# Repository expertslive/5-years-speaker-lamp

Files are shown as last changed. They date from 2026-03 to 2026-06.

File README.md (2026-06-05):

# High Five Hive — Setup Instructions

*Experts Live Netherlands · 5 Years · A thank you to our five-time speakers*

---

Thank you for being part of the Experts Live Netherlands community for **five years in a row**. This cube was made especially for you — a home for the four crystal cubes you collected at each edition, lit up to show them at their best.

Inside this box you'll find:

- The **High Five Hive** display cube (navy blue)
- A **USB-C power cable**
- Any spare screws or parts

---

## What's inside the cube

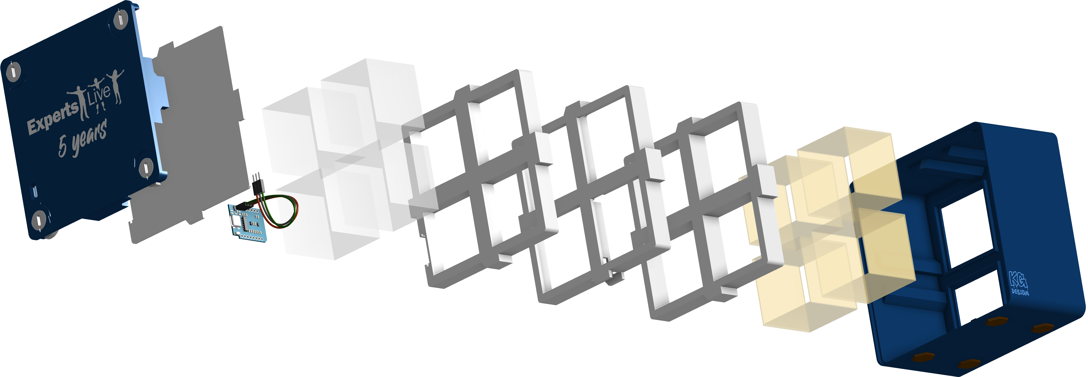
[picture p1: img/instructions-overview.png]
Overview of all components


The cube consists of several layers assembled from front to back:

- **Outer housing** — the dark navy blue shell
- **Crystal cube holders** — four individual compartments for each of your yearly speaker cubes
- **LED frames** — multiple layers holding the LED strip and cubes in place
- **Back cover plate** — the panel with the *Experts Live / 5 years* logo, secured by four twist-lock corner screws
- **WLED controller** — a tiny Wi-Fi-enabled electronics board (ESP8266) that drives all the lights and connects to your network

If you ever have to remove/place the inner frames, pay attention to the numbers on the side for correct placement:

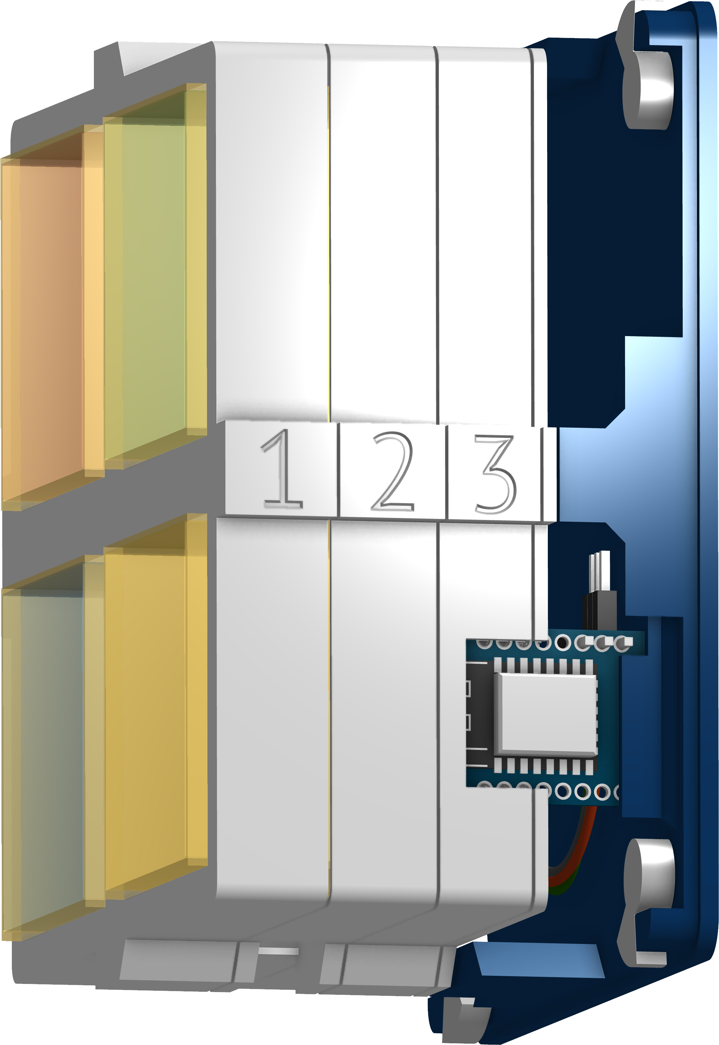
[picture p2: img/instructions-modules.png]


---

## Assembly

### Step 1 — Open the back cover

The back cover is secured by four **quarter-turn twist-lock screws** in the corners.

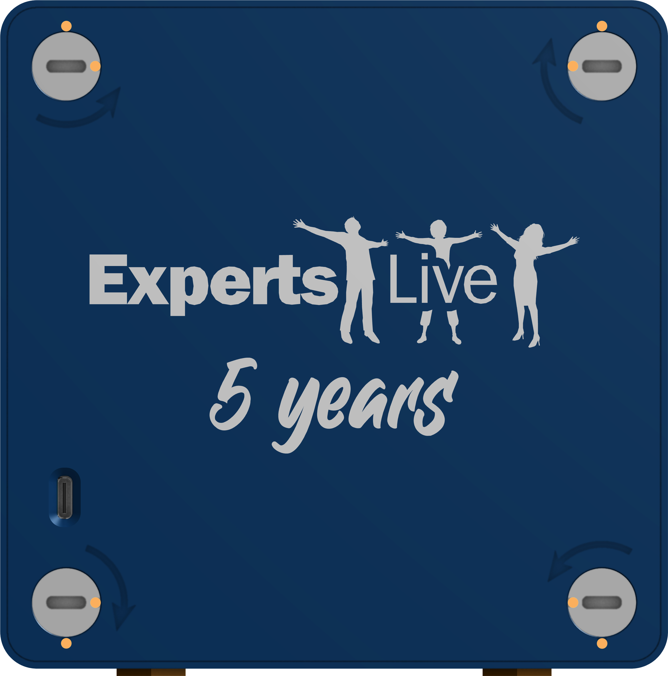
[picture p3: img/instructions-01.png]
Back cover with twist-lock screws


To open, insert the **connector end of the supplied USB-C cable** into each corner screw and rotate **in the opposite direction of the arrow**. Once all four screws are turned, the back panel will come free.

---

### Step 2 — Pull out the electronics board

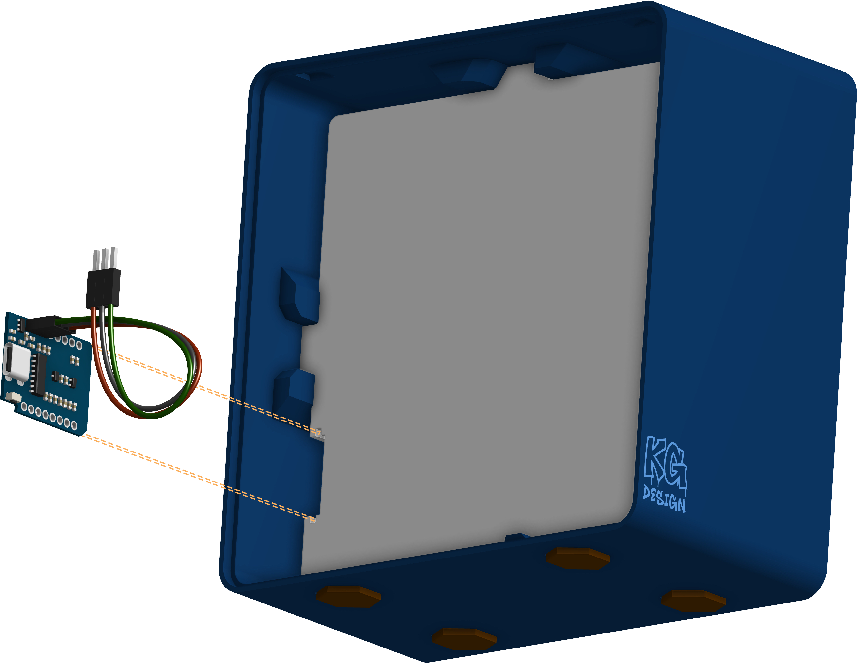
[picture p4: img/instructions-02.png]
ESP circuit board in housing


Gently pull the **WLED circuit board** out from its slot inside the housing. You only need to move it aside — **do not disconnect the LED strip connector** unless absolutely necessary.

> **If the LED strip connector did come loose**, reconnect it as follows before proceeding:
>
> | Wire colour | Pin | Position on circuitboard (viewed from above) |
> | --- | --- | --- |
> | **Red** | 5V | Left-most pin |
> | **Green** | Data | Middle pin |
> | **White** | GND | Right-most pin |

---

### Step 3 — Remove the white back panel

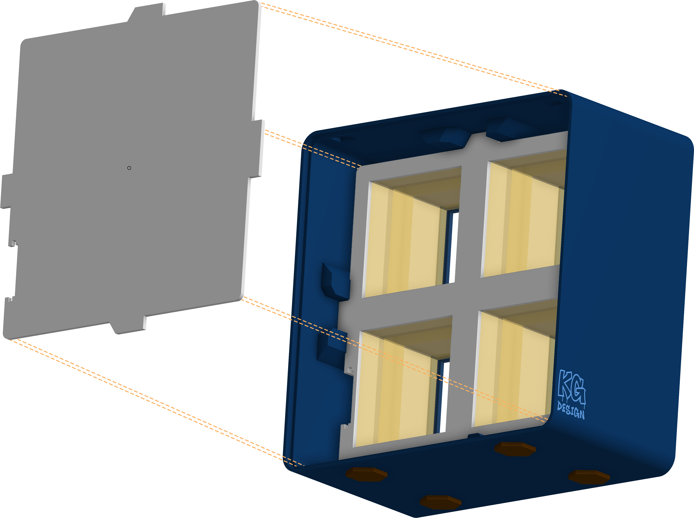
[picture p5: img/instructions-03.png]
White back panel removed


Lift out the **white cover plate** to expose the four openings for the crystal cubes inside the housing.

---

### Step 4 — Place your crystal cubes

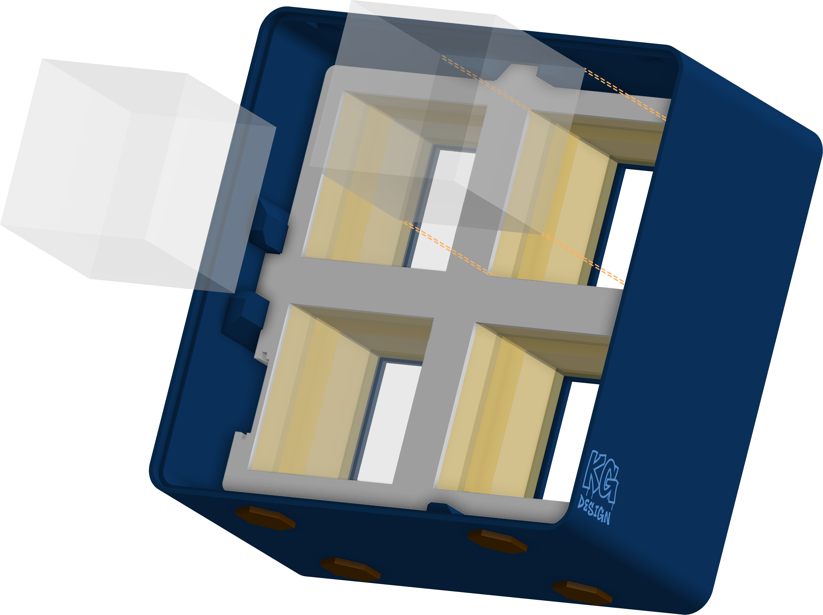
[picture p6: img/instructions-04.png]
Placing a crystal cube


Drop each of your four crystal speaker cubes into their compartment.

Each cube slides straight in and sits snugly in its slot. No forcing needed.

---

### Step 5 — Replace the white panel and reseat the board

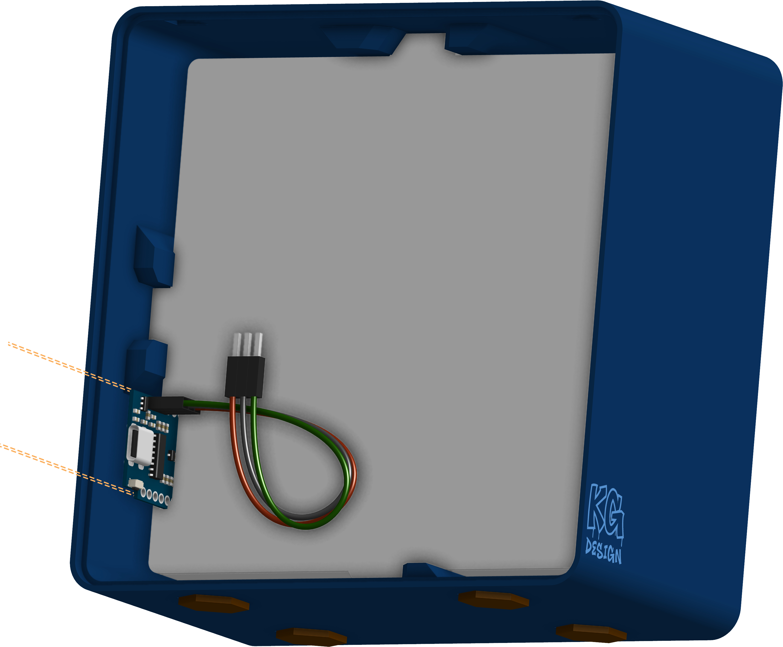
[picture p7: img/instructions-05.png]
Reseating the white panel and circuit board


Place the **white cover plate** back in position over the crystal cubes, then slide the **circuit board** back into its slot in the housing. Make sure the USB-C port aligns with the opening on the side of the back cover.

---

### Step 6 — Close and lock the back cover

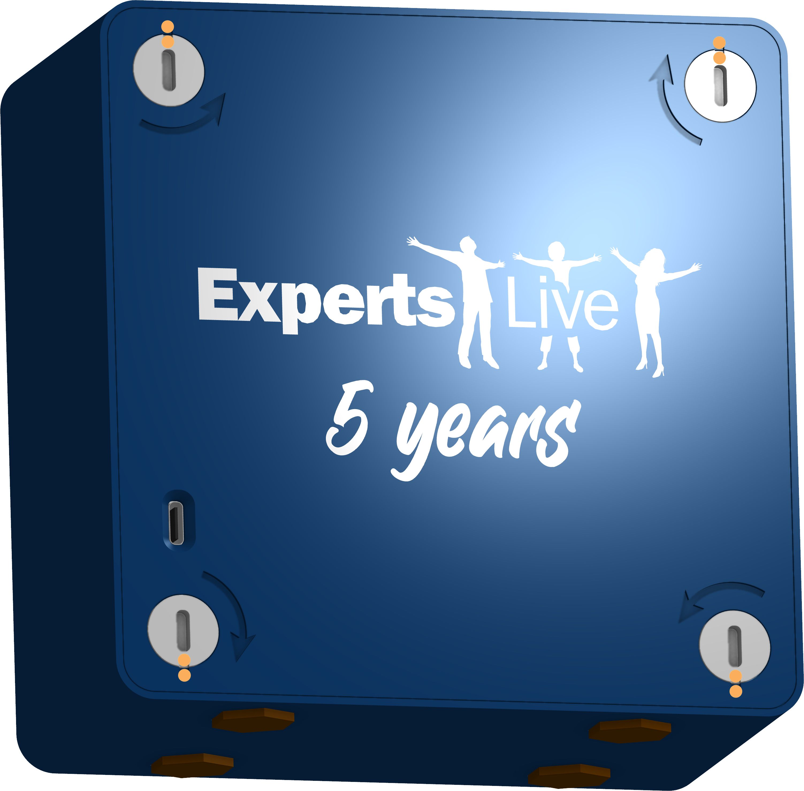
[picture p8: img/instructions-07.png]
Locking the back cover


Slide the back cover panel onto the housing and **lock all four corners in the direction of the arrows** using the USB-C connector. The arrows on the cover show the locked direction.

**Don't use excessive force!** If the screw wont turn freely, press down on the cover to make sure it slots in place neatly.

The cube is now fully assembled and ready to power on.

---

## Powering on

Connect a USB-C power cable (5V, at least 1A — a standard phone charger works perfectly) to the **USB-C port on the side** of the back panel.

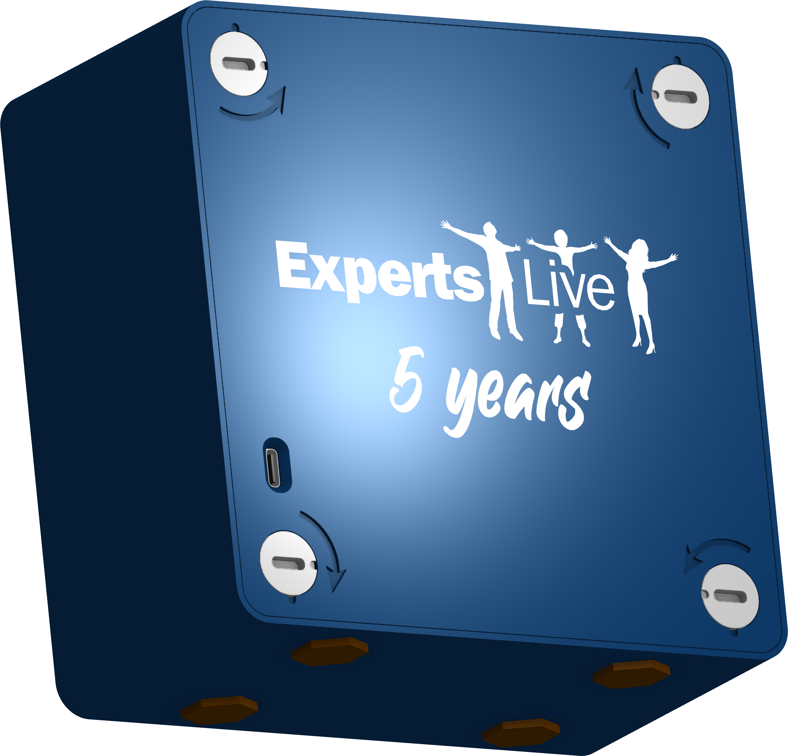
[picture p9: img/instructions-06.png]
USB-C port location


The cube will power on automatically. After a few seconds, the lights will start and the built-in show will begin — cycling through all the preset lighting effects.

---

## Connecting to the cube via Wi-Fi

The cube runs **WLED** — open-source LED control software with a built-in web interface. Out of the box it broadcasts its own open Wi-Fi network so you can connect and customise it without any technical setup.

### Step 1 — Connect to the cube's Wi-Fi

On your phone, tablet, or computer, open your Wi-Fi settings and connect to:

> **Network name:** `ExpertsLive-5-years`
> **Password:** wled1234

### Step 2 — Open the WLED interface

Once connected, open a browser and go to:

> **<http://expertslive.local>** (or <http://4.3.2.1>)

You will see the WLED interface with the custom Experts Live Netherlands background.

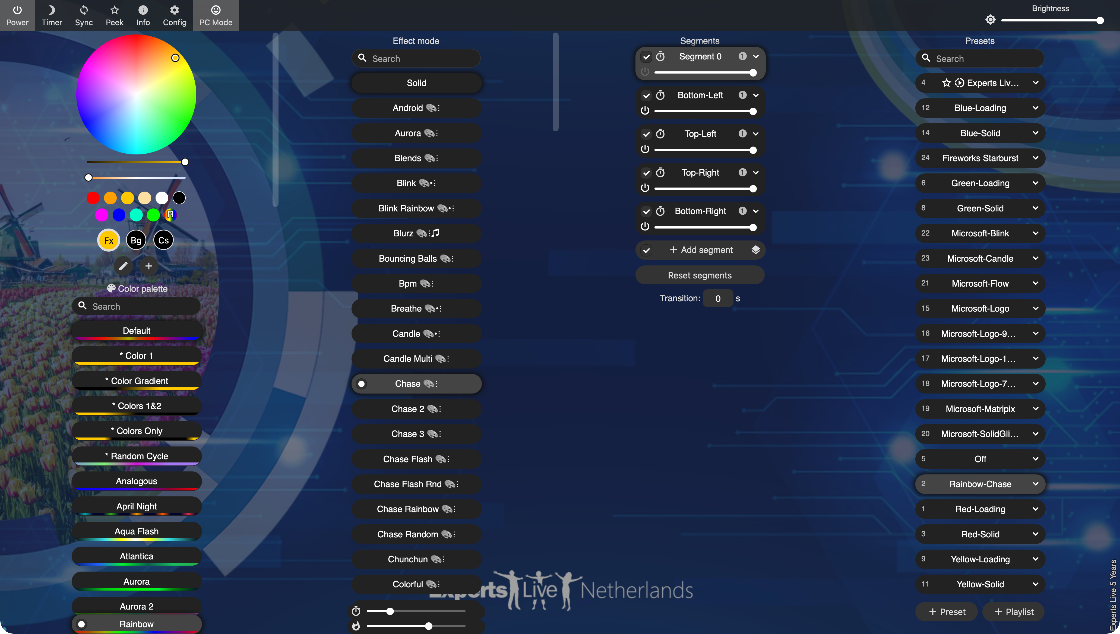
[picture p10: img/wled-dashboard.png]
WLED dashboard


### Using the WLED app (optional)

WLED has a free mobile app that makes it easy to control the cube from your phone. Search for **"WLED"** in the App Store or Google Play. When you open the app on the same Wi-Fi network, it will automatically discover the cube.

---

## Understanding the lights

The four cube compartments are each independently controlled. They are set up as named segments:

| Segment | Default colour |
| --- | --- |
| `Bottom-Left` | Blue |
| `Top-Left` | Red |
| `Top-Right` | Green |
| `Bottom-Right` | Yellow / Orange |

---

## Using the pre-built presets

A full set of lighting presets has been pre-loaded onto the cube. You can find them in the WLED interface under the **Presets** tab:

| Preset name | What it does |
| --- | --- |
| `Experts Live 5 Years` | **The main playlist** — cycles through all effects automatically |
| `Microsoft-Logo` | Each cube lights up in a Microsoft brand colour (blue / red / green / yellow) |
| `Microsoft-Matripix` | Matrix-style falling effect in brand colours |
| `Microsoft-Flow` | Smooth flowing colour per cube |
| `Microsoft-SolidGlitter` | Solid brand colours with a glitter sparkle |
| `Microsoft-Blink` | Fast blinking in brand colours |
| `Microsoft-Candle` | Warm candlelight flicker per cube |
| `Fireworks Starburst` | Fireworks bursting across all four cubes |
| `Rainbow-Chase` | A flowing rainbow chase across all four cubes |
| `Microsoft-Logo-90/180/270deg` | Microsoft colours rotated, used as a `boot sequence` |
| `Red/Green/Blue/Yellow-Solid/Loading` | Each cube individually lit in a single solid colour, used as a `boot sequence` |
| `Off` | All lights off, used as a `boot sequence` |

### The default playlist

By default, when you power the cube on it will automatically start the **"Experts Live 5 Years"** playlist. This cycles through all the presets in a scripted sequence — it starts with a loading animation, builds up to all four cubes lit and runs through the Microsoft-themed effects.
You don't need to do anything — just plug it in and enjoy the show.

If you want to set one preset as default, you can select the preset als make sure `Apply at boot` is selected before you click `Save`.

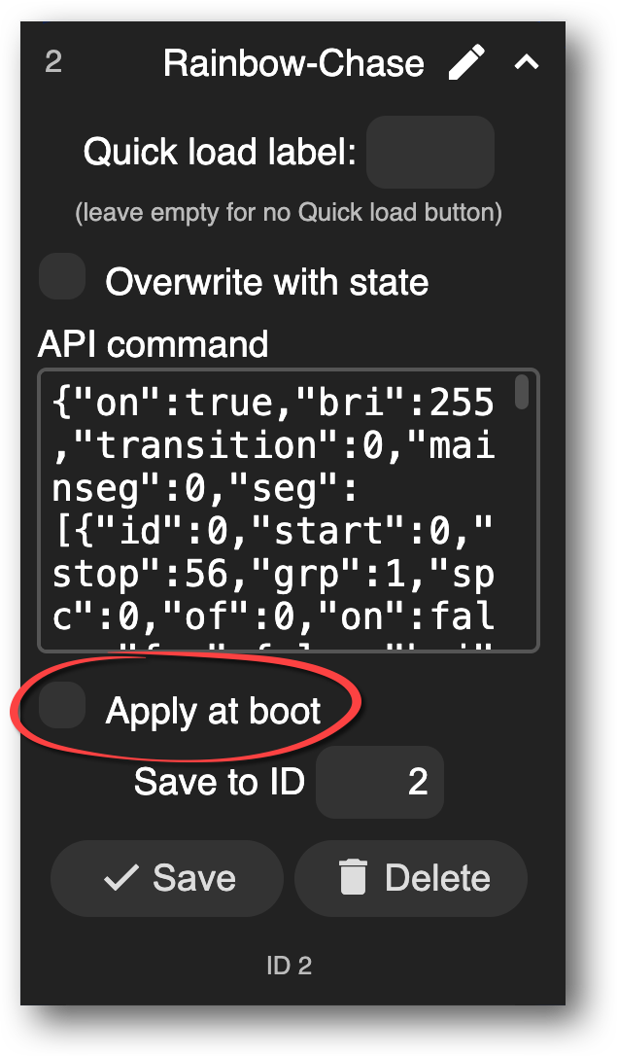
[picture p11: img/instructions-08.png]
Setting a preset


---

## Connecting to your home Wi-Fi (optional)

If you'd like to control the cube from your normal home network (so you don't need to switch Wi-Fi on your phone every time), you can connect it to your router:

1. Connect to `ExpertsLive-5-years` and open **<http://expertslive.local>** (or <http://4.3.2.1>)
2. Go to **Config → WiFi Setup**
3. Enter your home Wi-Fi network name and password and click **Save**
4. The cube will restart and join your home network
5. You can now reach it at **http://expertslive.local** from any device on the same network

> **Note:** After connecting to your home Wi-Fi, the `ExpertsLive-5-years` hotspot will no longer appear and will only show up if the device is unable to connect to a known network.

---

## Tips

- **Power:** Any USB-C charger (phone charger, laptop USB-C port, USB hub) will work. The cube draws under 1A at full brightness.
- **Brightness:** You can dim the lights in the WLED interface using the brightness slider — useful if you use it as a night-light ambience.
- **Custom effects:** WLED has hundreds of built-in effects and palettes. Feel free to explore — nothing you change can break the cube, and the pre-built presets are always there to return to.

---

## About this cube

Designed and built by [**Koos Goossens**](https://www.linkedin.com/in/koos-goossens/) for [Experts Live Netherlands](https://www.expertslive.nl)

This cube was created to give the four crystal cubes you earned over the years a permanent home and to say **thank you** for your continued contribution to the Microsoft community! 🙏🏻

*See you at the next one.*

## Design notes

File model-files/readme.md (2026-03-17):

# Model Files — High Five Hive

This folder contains all printable files for the ***"High Five Hive"*** speaker lamp, including the master Bambu Studio project file and the individual STL components.

---

## Project file

**`experts-live-high-five-hive.3mf`** — the Bambu Studio project file containing all four build plates, pre-arranged with their settings, filament assignments, and plate configurations. Open this file in Bambu Studio to print directly without any manual setup.

All plate settings (layer height, supports, print sequence) are embedded in the `.3mf`. A **textured PEI plate** is strongly recommended for both the housing and the rear cover to get a nice surface finish on the visible exterior faces.

---

## Build plates

| # | Plate | Contents | Material | Notes |
| --- | --- | --- | --- | --- |
| 1 | [Main housing](#plate-1--main-housing) | Outer shell | Dark Blue Matte PLA | Fuzzy skin on all exterior surfaces |
| 2 | [Rear cover](#plate-2--rear-cover) | Cover body, logo letters, mascot, screws, supports | Dark Blue + Ash Grey Matte PLA | Multi-material; many small objects |
| 3 | [Inner modules](#plate-3--inner-modules) | Cube holders, LED frame, holder plate | Ivory White Matte PLA | Single material |
| 4 | [Transparent cubes](#plate-4--transparent-cubes) | Light diffusion cubes (3 of 4) | Translucent PLA — Mellow Yellow | Vase mode; 0.8 mm nozzle; print 4th cube separately |

---

### Plate 1 — Main housing

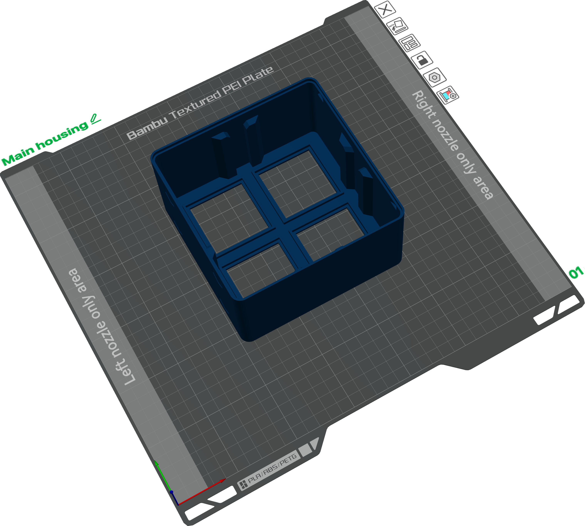
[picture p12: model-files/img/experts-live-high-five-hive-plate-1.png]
Plate 1 — Main housing


The outer dark navy blue shell of the lamp. Printed as a single object.

**Fuzzy skin** is applied to all exterior surfaces to give the housing a soft matte texture that hides layer lines and matches the look of the crystal speaker cubes.

| File | Description |
| --- | --- |
| `experts-live-high-five-hive-housing-main.stl` | Outer housing shell |

- **Material:** Bambu Labs Matte PLA — Dark Blue
- **Plate:** Textured PEI plate strongly recommended

---

### Plate 2 — Rear cover

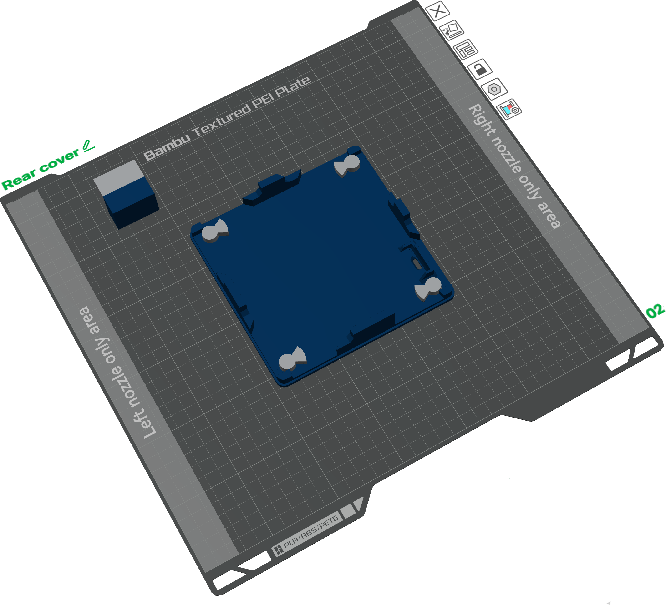
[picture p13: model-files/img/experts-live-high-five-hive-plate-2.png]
Plate 2 — Rear cover


The back panel with the *Experts Live / 5 Years* branding and the four quarter-turn twist-lock screws. This is a multi-material plate combining Dark Blue for the cover body and Ash Grey for the raised logo, lettering, and screw hardware.

The cover is intentionally built from many small individual objects rather than one solid model:

- **Individual letters** for "EXPERTS LIVE" and "5 YEARS" are separate STLs, allowing precise colour assignment to each character without painting.
- **Mascot logo** is split into multiple parts for the same reason.
- **Key supports** are custom-designed objects placed around each screw to prevent the screw from fusing with the cover during printing. They are printed in Ash Grey and can be broken free cleanly after the print.

| File | Description |
| --- | --- |
| `experts-live-high-five-hive-housing-cover.stl` | Main cover body |
| `experts-live-high-five-hive-housing-cover-01-ex.stl` … `09-e.stl` | Individual letters — *Experts Live* |
| `experts-live-high-five-hive-housing-cover-10-mascotte-*.stl` | Experts Live mascot logo (multiple parts) |
| `experts-live-high-five-hive-housing-cover-11-5.stl` … `16-S.stl` | Individual letters — *5 Years* |
| `experts-live-high-five-hive-screw-1.stl` … `screw-4.stl` | Quarter-turn twist-lock screws |
| `experts-live-high-five-hive-screw-1-key-support.stl` … `screw-4-key-support.stl` | Screw key supports (prevent fusing) |

- **Materials:** Bambu Labs Matte PLA — Dark Blue (cover body) + Ash Grey (logo, letters, screws, key supports)
- **Plate:** Textured PEI plate strongly recommended

---

### Plate 3 — Inner modules

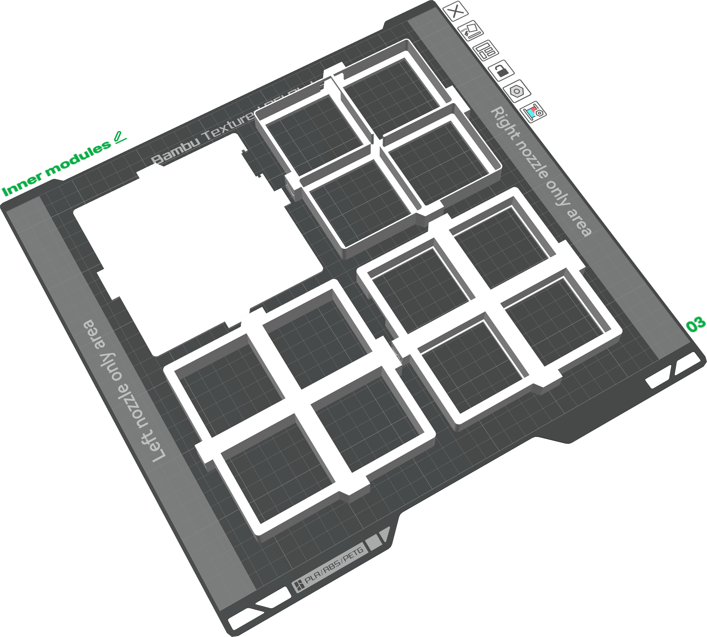
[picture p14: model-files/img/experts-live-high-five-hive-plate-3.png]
Plate 3 — Inner modules


The internal structural parts that hold the LED strip and crystal cubes in position inside the housing. All parts are printed in Ivory White.

| File | Description |
| --- | --- |
| `experts-live-high-five-hive-1-cube-holder.stl` | Cube holder frame — type 1 |
| `experts-live-high-five-hive-2-led-frame.stl` | LED strip frame |
| `experts-live-high-five-hive-3-cube-holder.stl` | Cube holder frame — type 3 |
| `experts-live-high-five-hive-3-cube-holder-plate.stl` | Cube holder backing plate |

- **Material:** Bambu Labs Matte PLA — Ivory White

---

### Plate 4 — Transparent cubes

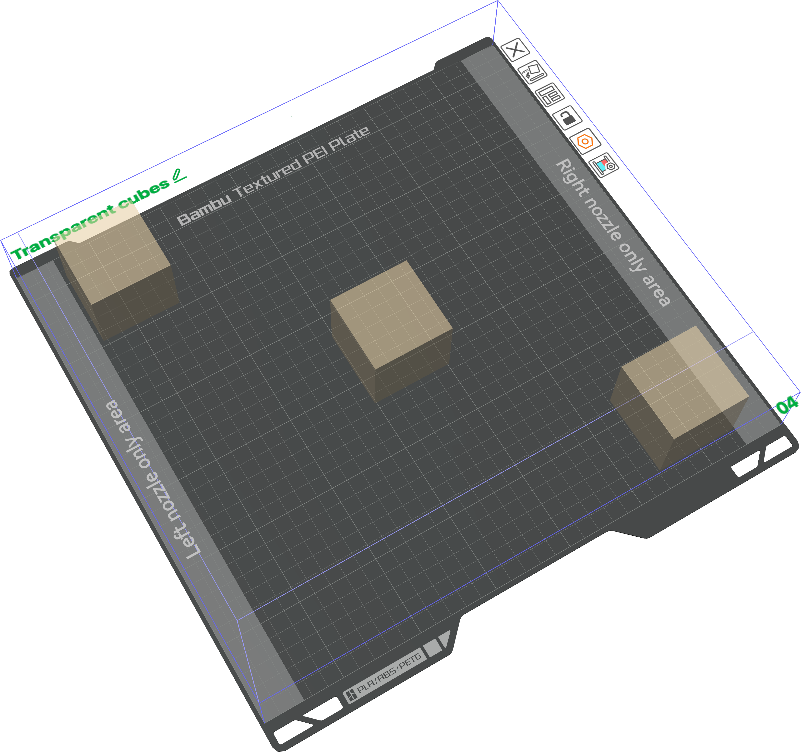
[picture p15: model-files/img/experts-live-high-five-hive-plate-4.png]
Plate 4 — Transparent cubes


The four small light-diffusion cubes that sit inside each compartment and scatter the LED light through the crystal speaker cubes above them. Three cubes are printed on this plate; **the fourth must be sent as a separate print**.

These cubes are printed in **vase mode** (single continuous spiral wall, no top/bottom layers) to maximise translucency and light diffusion.

- **Material:** Bambu Labs Translucent PLA — Mellow Yellow
- **Print sequence:** By object (sequential) — required for vase mode with multiple objects on one plate
- **Nozzle:** 0.8 mm recommended for a thicker, more even wall and better light diffusion
- **Plate:** Print 3 cubes first, then send a second print for cube #4

---

## Materials summary

| Material | Colour | Used for |
| --- | --- | --- |
| Bambu Labs Matte PLA | Dark Blue | Housing shell, rear cover body |
| Bambu Labs Matte PLA | Ash Grey | Logo letters, mascot, screws |
| Bambu Labs Matte PLA | Ivory White | All inner structural modules |
| Bambu Labs Translucent PLA | Mellow Yellow | Inner light-diffusion cubes |

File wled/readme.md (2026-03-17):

# WLED Configuration Files

This folder contains the WLED configuration for the **5 Years** speaker cubes lamp. Use these files to restore or clone the device if the ESP8266 controller needs to be replaced or reset.

---

## Files

| File | Purpose |
| --- | --- |
| `wled_cfg_experts-live-5-years.json` | Full device configuration (network, hardware, LED settings) |
| `wled_presets_experts-live-5-years.json` | All lighting presets and the boot playlist |
| `wled_ledmap.json` | Custom LED index remap for the physical strip layout |
| `wled-ui-bg-expertslive.jpg` | Custom background image shown in the WLED web UI |

---

## Device configuration summary

| Setting | Value |
| --- | --- |
| Device name | `Experts Live 5 Years` |
| mDNS hostname | `expertslive` → `http://expertslive.local` |
| Access point SSID | `ExpertsLive-5-years` (open, no password) |
| Access point IP | `4.3.2.1` |
| LED count | 56 |
| LED type | WS2812B |
| GPIO pin | 2 |
| Max current | 950 mA |
| Target FPS | 42 |
| Default brightness | 128 / 255 (~50%) |
| Boot preset | `4` — Experts Live 5 Years (playlist) |

---

## Presets

| ID | Name | Description |
| --- | --- | --- |
| `4` | `Experts Live 5 Years` | **Main boot playlist** — cycles through all effects automatically |
| `15` | `Microsoft-Logo` | Each cube in a Microsoft brand colour (blue / red / green / yellow) |
| `16` | `Microsoft-Logo-90deg` | Brand colours rotated 90° — used in boot sequence |
| `17` | `Microsoft-Logo-180deg` | Brand colours rotated 180° — used in boot sequence |
| `18` | `Microsoft-Logo-720deg` | Brand colours rotated 270° — used in boot sequence |
| `19` | `Microsoft-Matripix` | Matrix-style falling pixels in brand colours |
| `20` | `Microsoft-SolidGlitter` | Solid brand colours with glitter sparkle |
| `21` | `Microsoft-Flow` | Smooth flowing colour per cube |
| `22` | `Microsoft-Blink` | Fast blink in brand colours |
| `23` | `Microsoft-Candle` | Warm candlelight flicker per cube |
| `24` | `Fireworks Starburst` | Fireworks bursting across all four cubes |
| `2` | `Rainbow-Chase` | Flowing rainbow chase across all four cubes |
| `3` | `Red-Solid` | All cubes solid red |
| `8` | `Green-Solid` | All cubes solid green |
| `11` | `Yellow-Solid` | All cubes solid yellow |
| `14` | `Blue-Solid` | All cubes solid blue |
| `1` | `Red-Loading` | Red loading animation — used in boot sequence |
| `6` | `Green-Loading` | Green loading animation — used in boot sequence |
| `9` | `Yellow-Loading` | Yellow loading animation — used in boot sequence |
| `12` | `Blue-Loading` | Blue loading animation — used in boot sequence |
| `5` | `Off` | All LEDs off — used at end of boot sequence |

---

## LED map

The physical LED strip is wired so that three LEDs at the end of the strip (indices 53, 54, 55) are physically located after LED 10. The `wled_ledmap.json` remaps the logical indices to match the physical positions, ensuring segment boundaries align correctly with the four cube compartments.

---

## Restoring to a new device

1. Flash the device with [WLED](https://install.wled.me) (v0.15 or later recommended).
2. Connect to the `WLED-xxxxxx` access point and open `http://4.3.2.1`.
3. Go to **Config → Security & Updates** and upload `wled_presets_experts-live-5-years.json` under `Restore presets` using the **Restore** option.
4. Go to **Config → Security & Updates** and upload `wled_cfg_experts-live-5-years.json` unser `Restore configuration` using the **Restore** option.
5. Go to `http://expertslive.local/edit`, create a new file named `ledmap.json`, and paste in the contents of `wled_ledmap.json`.
6. Go to **Config → User Interface** and set `BG image URL` to `https://github.com/expertslive/5-years-speaker-lamp/blob/main/wled/wled-ui-bg-expertslive.jpg?raw=true`
7. Reboot the device. It will start the boot playlist automatically.

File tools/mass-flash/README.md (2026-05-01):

# WLED Mass-Flash Tool

Flashes multiple ESP8266 boards with WLED 0.15 + Experts Live 5 Years config in one USB step per board. After each flash the script discovers the board's IP on the local network (via MAC in ARP) and prints a clickable URL.

## Prerequisites (one-time, macOS)

    brew install esptool jq

`littlefs-python` is installed on demand by `build-fs.sh` via `python3 -m pip`.

If your boards use a CH340 USB-serial chip (common on cheap clones), install the WCH driver from https://www.wch.cn/downloads/CH341SER_MAC_ZIP.html.

## Build (once)

    WLED_WIFI_PSK='<wifi-password>' \
    WLED_AP_PSK='<device-ap-password>' \
    WLED_OTA_PASSWORD='<ota-password>' \
    ./build-fs.sh

Downloads the WLED 0.15.0 ESP8266 firmware and builds `build/littlefs.bin` containing:

- `cfg.json` — device config (LED count, boot preset, hardware pins, mDNS name)
- `wsec.json` — Wi-Fi/AP/OTA credentials supplied from environment variables
- `presets.json` — all lighting presets and the Experts Live boot playlist
- `ledmap.json` — physical-to-logical LED index remap

## Flash a single board

    ./flash.sh

Plug in the ESP8266 via USB, run the command, wait ~75s, unplug.

## Flash multiple boards in a loop

    ./flash.sh --loop

The script waits for a USB-serial device, flashes it, prints the board's IP, then waits for you to unplug before moving on to the next.

## Flash one specific port (when multiple devices are plugged in)

    ./flash.sh --port /dev/cu.usbserial-10

Useful on a workstation that hosts multiple flashing sessions at the same time.

## IP discovery overrides

By default `flash.sh` uses the interface from `route get default` and sweeps that interface's `/24` prefix. Override this when the active LAN is not on the default interface or when you need to force the scan range:

    ./flash.sh --iface en0
    ./flash.sh --subnet 192.168.1.0/24

## Per-flash output

    Board #7: /dev/cu.usbserial-10 -> MAC aa:bb:cc:dd:ee:ff -> http://192.168.1.123

Open the URL to verify the board joined Wi-Fi and is playing the boot playlist.

## Implementation notes

**LittleFS version:** WLED 0.15 on ESP8266 uses LittleFS v2.0 with `name_max=32`. `brew mklittlefs` writes v2.11 with `name_max=255` which WLED silently refuses to mount (it then reformats the partition with defaults, throwing away our config). We build the image via `littlefs-python` with the on-device parameters: `disk_version=0x00020000`, `name_max=32`, `block_size=8192`, `block_count=125` (total 1,024,000 bytes).

**Partition offset:** LittleFS lives at flash offset `0x300000` in WLED's ESP8266 4m1m partition layout. Not `0x200000` — a common misconfiguration.

**Credential storage:** WLED splits credentials between `cfg.json` (SSID + password length fields) and `wsec.json` (plaintext secrets). Injecting `psk` into `cfg.json` has no effect; credentials must be supplied through environment variables and written into `wsec.json` at build time.

**mDNS collisions:** all boards claim the same mDNS name `expertslive`. Only one can hold the name at a time, so hostname-based discovery (`expertslive.local`) is unreliable in bulk. The script uses ARP + MAC match instead — reliable even with many identical devices on one LAN.

**BG image URL (optional, per-browser):** WLED 0.15 stores the UI background URL in `localStorage`, not on the device, so it cannot be baked into the firmware image. Recipients who want the Experts Live background can set it themselves at **Config → User Interface → BG image URL** to:

    https://github.com/expertslive/5-years-speaker-lamp/blob/main/wled/wled-ui-bg-expertslive.jpg?raw=true

This is a one-time per-browser setting and does not affect LED behavior.

## Troubleshooting

**Board not detected:** Check the USB cable (some are charge-only). For CH340 clones, install the WCH driver.

**`Could not open <port>, the port is busy`:** another process is holding the serial port. Close any `install.wled.me` browser tab or other Web-Serial session, then retry.

**`Failed to connect to ESP8266`:** some clone boards don't auto-reset. Hold GPIO0 to GND while plugging in, then release.

**Device boots but doesn't join Wi-Fi:** verify the required `WLED_*` environment variables were set before building. Rebuild with `./build-fs.sh` if needed.

**IP not found within 60s:** the board flashed successfully but hasn't joined Wi-Fi yet, or the wrong LAN was scanned. Wait another 30s and check your router's DHCP list, or re-run with `--iface <name>` / `--subnet <prefix>`.

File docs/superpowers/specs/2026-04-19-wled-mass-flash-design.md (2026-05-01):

# WLED Mass-Flash Tool — Design

**Date:** 2026-04-19
**Context:** Flashing multiple ESP8266 boards with WLED + event-specific config for the Experts Live 5 Years speaker lamp.

## Problem

The current manual per-board process (see `wled/readme.md`) takes ~10–15 minutes per device: flash firmware via browser web installer, connect to device AP, upload presets JSON via web UI, upload config JSON via web UI, create `ledmap.json` via `/edit`, set BG image URL via UI, reboot. For multiple boards that becomes tedious AP-switching and file uploads.

We want a USB-only workflow: plug in, run one command, unplug.

## Approach

Flash **firmware + a pre-built LittleFS filesystem image** in a single `esptool` invocation. The LittleFS image contains the WLED config, presets, LED map, and generated secret config that WLED reads at boot, so the device comes up fully configured — no AP dance, no web UI steps.

Rejected alternatives:
- **Post-flash HTTP provisioning** (flash firmware, then script POSTs to WLED's JSON API): requires each Mac to hop onto each WLED AP in sequence. Fragile on macOS.
- **Parallel flashing via USB hub**: sequential is simple enough for this batch. Not worth the added complexity.

## Deliverables

New folder `tools/mass-flash/` in the repo:

```
tools/mass-flash/
├── flash.sh              # main — flashes one board per invocation (optional loop mode)
├── build-fs.sh           # one-time — builds LittleFS image from wled/ JSONs
├── build/                # gitignored — generated artifacts
│   ├── WLED_0.15.0_ESP8266.bin    # firmware (downloaded on first build)
│   ├── littlefs.bin                # filesystem image
│   ├── cfg-baked.json              # config copied from wled/ for the FS image
│   └── wsec-baked.json             # generated from WLED_* env vars, not committed
└── README.md
```

## Config transformations

The baked `cfg.json` derives from `wled/wled_cfg_experts-live-5-years.json`. Plaintext credentials are not committed; `build-fs.sh` generates `wsec.json` from environment variables at build time.

1. **Credentials** — WLED's export format uses password-length fields in `cfg.json` and stores plaintext values in `wsec.json`. The build step requires `WLED_WIFI_PSK`, `WLED_AP_PSK`, and `WLED_OTA_PASSWORD`, plus optional MQTT/Hue values, and writes them only into the generated build artifact.

2. **BG image URL** — WLED 0.15 stores this browser-side in `localStorage`, so it cannot be baked into the device image. The README documents it as an optional one-time per-browser setting.

`presets.json` and `ledmap.json` go into the LittleFS image unchanged.

## Flash command

```
esptool --port $(auto-detect) write-flash \
  0x0        build/WLED_0.15.0_ESP8266.bin \
  0x300000   build/littlefs.bin
```

The LittleFS partition offset depends on the WLED build's partition map and must be confirmed against the official WLED ESP8266 partition layout before first flash.

Port auto-detection: scan `/dev/cu.usbserial-*` and `/dev/cu.wchusbserial-*`. If exactly one match, use it. If zero or multiple, prompt the user.

## Per-board workflow

1. Plug ESP8266 into USB.
2. Run `./flash.sh`.
3. Script writes firmware + LittleFS, reads the board MAC via `esptool read-mac`, then discovers the DHCP IP by matching that MAC in ARP.
4. Script prints the discovered URL, or a clear "IP not found" warning if the board has not joined Wi-Fi yet.
5. (Optional) loop mode: script waits for device disconnect, then reconnect, then repeats automatically.

## Dependencies (macOS, one-time)

```
brew install esptool jq
```

`build-fs.sh` installs `littlefs-python` with `python3 -m pip` if needed so the same interpreter imports the module later. If the WCH USB-serial driver is not already installed, some boards (CH340-based clones) will not enumerate.

## Phases

1. **Build tooling** — write `build-fs.sh`, `flash.sh`, README. Produce `littlefs.bin` with current (untransformed) JSONs to verify the filesystem build process.
2. **Test on 1 board** — flash once, verify:
   - Device boots and joins the configured Wi-Fi network
   - Boot preset (playlist 4) plays
   - LED map is active (correct cube segmentation)
  - BG URL remains an optional per-browser setting
3. **Document BG URL limitation** — keep BG URL as an optional per-browser setting because it is not stored on the device.
4. **Flash remaining boards** — sequential, optionally with loop mode.

## Unknowns resolved in phase 2

- BG image URL is browser-local in WLED 0.15 and cannot be baked into the device.
- Generated `wsec.json` credentials are the correct way to provide Wi-Fi/AP/OTA secrets.
- LittleFS partition offset for the official WLED ESP8266 binary is `0x300000`.

## Success criteria

- A fresh ESP8266 plugged into USB, with one invocation of `flash.sh`, boots into the Experts Live 5 Years playlist with correct LED mapping and correct Wi-Fi connection — no AP-switching or web UI upload steps.
- Total hands-on time stays low because each board is plug in, flash, unplug.

## Out of scope

- Parallel flashing via USB hub
- Per-board unique identifiers (mDNS collisions, MQTT client IDs) — each unit will live on a different network post-event
- Automated GitHub Actions CI for the tool — one-time event use

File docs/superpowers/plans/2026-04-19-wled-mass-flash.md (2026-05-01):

# WLED Mass-Flash Tool Implementation Plan

> **For agentic workers:** REQUIRED SUB-SKILL: Use superpowers:subagent-driven-development (recommended) or superpowers:executing-plans to implement this plan task-by-task. Steps use checkbox (`- [ ]`) syntax for tracking.

**Goal:** Build a USB-only flashing workflow (`flash.sh`) that takes a blank ESP8266 to a fully configured WLED device in a single command, so multiple Experts Live speaker-lamp boards can be provisioned in one sitting.

**Architecture:** Two bash scripts in `tools/mass-flash/`. `build-fs.sh` runs once to download the WLED firmware binary, generate `wsec.json` from environment variables, and build a LittleFS image from the JSON files in `wled/`. `flash.sh` runs once per board: auto-detects the USB-serial port, runs `esptool write-flash` with firmware + filesystem, reads the board MAC, and discovers the DHCP IP via ARP. The device comes up fully configured on the target WLAN with the correct boot playlist and LED map — no web UI uploads or AP-switching.

**Tech Stack:** bash, `esptool` (Python), `littlefs-python`, `curl` (firmware download), `jq` (JSON transformations). macOS host.

**Test strategy:** Bash tooling does not warrant unit-test infrastructure for a one-shot event. Each task ends with a **verification step** — run the script (or a fragment), inspect the output, confirm expectations. Phase 2 of the spec (one-board end-to-end test with real hardware) is the integration test.

**Implementation outcome:** The final implementation uses `esptool`, `littlefs-python`, a 1,024,000-byte LittleFS image at `0x300000`, `wsec.json` generated from environment variables, and ARP/MAC IP discovery. The BG image cannot be baked because WLED 0.15 stores it in browser `localStorage`.

---

## Task 1: Scaffold folder + README skeleton + .gitignore

**Files:**
- Create: `tools/mass-flash/README.md`
- Create: `tools/mass-flash/.gitignore`
- Create: `tools/mass-flash/build/.gitkeep`

- [ ] **Step 1: Create folder structure**

```bash
mkdir -p tools/mass-flash/build
touch tools/mass-flash/build/.gitkeep
```

- [ ] **Step 2: Write `.gitignore` to exclude built artifacts**

`tools/mass-flash/.gitignore`:
```
build/*
!build/.gitkeep
```

- [ ] **Step 3: Write README skeleton**

`tools/mass-flash/README.md`:
```markdown
# WLED Mass-Flash Tool

Flashes multiple ESP8266 boards with WLED + Experts Live 5 Years config in one USB step per board.

## Prerequisites (one-time, macOS)

    brew install esptool jq

`littlefs-python` is installed on demand by `build-fs.sh` via `python3 -m pip`.

If your boards use a CH340 USB-serial chip (common on cheap clones), install the WCH driver from https://www.wch.cn/downloads/CH341SER_MAC_ZIP.html.

## Build (once)

    ./build-fs.sh

Downloads the WLED firmware and builds `build/littlefs.bin` with baked config.

## Flash a single board

    ./flash.sh

Plug in the ESP8266 via USB, run the command, wait ~45s, unplug.

## Flash in a loop (for multiple boards)

    ./flash.sh --loop

Script waits for each new USB-serial device, flashes it, prompts for the next.
```

- [ ] **Step 4: Verify structure**

```bash
ls -la tools/mass-flash/
```
Expected: `.gitignore`, `README.md`, `build/` directory present.

- [ ] **Step 5: Commit**

```bash
git add tools/mass-flash/
git commit -m "Scaffold tools/mass-flash/ folder and README"
```

---

## Task 2: Dependency-check preamble in build-fs.sh

**Files:**
- Create: `tools/mass-flash/build-fs.sh`

- [ ] **Step 1: Write dependency-check script**

`tools/mass-flash/build-fs.sh`:
```bash
#!/usr/bin/env bash
set -euo pipefail

SCRIPT_DIR="$(cd "$(dirname "${BASH_SOURCE[0]}")" && pwd)"
REPO_ROOT="$(cd "$SCRIPT_DIR/../.." && pwd)"
BUILD_DIR="$SCRIPT_DIR/build"
WLED_DIR="$REPO_ROOT/wled"

require_cmd() {
  if ! command -v "$1" >/dev/null 2>&1; then
    echo "Missing: $1" >&2
    echo "Install with: $2" >&2
    exit 1
  fi
}

require_cmd esptool "brew install esptool"
require_cmd jq "brew install jq"
require_cmd curl "already in macOS"
require_cmd python3 "already in macOS"

mkdir -p "$BUILD_DIR"

echo "Dependencies OK."
```

- [ ] **Step 2: Make executable**

```bash
chmod +x tools/mass-flash/build-fs.sh
```

- [ ] **Step 3: Verify**

```bash
./tools/mass-flash/build-fs.sh
```
Expected: prints `Dependencies OK.` (install anything missing first).

- [ ] **Step 4: Commit**

```bash
git add tools/mass-flash/build-fs.sh
git commit -m "build-fs.sh: dependency preamble"
```

---

## Task 3: Firmware download in build-fs.sh

**Files:**
- Modify: `tools/mass-flash/build-fs.sh`

**Note on firmware source:** WLED's GitHub releases publish ESP8266 binaries at predictable URLs. The 0.15.0 ESP8266 release asset is `WLED_0.15.0_ESP8266.bin`. If WLED has published a newer 0.15.x stable, upgrade at the top of the script — there is no compelling reason to pin. Pin to a version this plan was tested with: **0.15.0**.

- [ ] **Step 1: Append firmware-download block**

Add to `tools/mass-flash/build-fs.sh` (after dependency checks):

```bash
WLED_VERSION="0.15.0"
FIRMWARE_URL="https://github.com/Aircoookie/WLED/releases/download/v${WLED_VERSION}/WLED_${WLED_VERSION}_ESP8266.bin"
FIRMWARE_BIN="$BUILD_DIR/WLED_${WLED_VERSION}_ESP8266.bin"

if [[ ! -f "$FIRMWARE_BIN" ]]; then
  echo "Downloading WLED $WLED_VERSION firmware..."
  curl -fL --retry 3 -o "$FIRMWARE_BIN" "$FIRMWARE_URL"
fi

ls -la "$FIRMWARE_BIN"
```

- [ ] **Step 2: Run**

```bash
./tools/mass-flash/build-fs.sh
```
Expected: downloads the `.bin` file, prints size. File should be between ~500KB and ~800KB (typical WLED ESP8266 binary).

- [ ] **Step 3: Verify it is a valid ESP8266 image**

```bash
esptool --chip esp8266 image-info tools/mass-flash/build/WLED_0.15.0_ESP8266.bin
```
Expected: output shows ESP8266 image header, segments, entry point — no parse errors.

- [ ] **Step 4: Commit**

```bash
git add tools/mass-flash/build-fs.sh
git commit -m "build-fs.sh: download and verify WLED ESP8266 firmware"
```

---

## Task 4: Generate wsec-baked.json from environment credentials

**Files:**
- Modify: `tools/mass-flash/build-fs.sh`

**Why this works:** WLED's config exporter replaces plaintext secrets with password-length fields to avoid leaking credentials. WLED reads plaintext values from `wsec.json`, so `build-fs.sh` generates that file from environment variables instead of storing secrets in Git.

- [ ] **Step 1: Append cfg/wsec generator**

Add to `tools/mass-flash/build-fs.sh`:

```bash
SOURCE_CFG="$WLED_DIR/wled_cfg_experts-live-5-years.json"
BAKED_CFG="$BUILD_DIR/cfg-baked.json"
BAKED_WSEC="$BUILD_DIR/wsec-baked.json"

: "${WLED_WIFI_PSK:?Set WLED_WIFI_PSK before running build-fs.sh}"
: "${WLED_AP_PSK:?Set WLED_AP_PSK before running build-fs.sh}"
: "${WLED_OTA_PASSWORD:?Set WLED_OTA_PASSWORD before running build-fs.sh}"
WLED_MQTT_PSK="${WLED_MQTT_PSK:-}"
WLED_HUE_KEY="${WLED_HUE_KEY:-}"

if [[ ! -f "$SOURCE_CFG" ]]; then
  echo "Missing source config: $SOURCE_CFG" >&2
  exit 1
fi

cp "$SOURCE_CFG" "$BAKED_CFG"

jq -n \
  --arg wifi_psk "$WLED_WIFI_PSK" \
  --arg ap_psk "$WLED_AP_PSK" \
  --arg mqtt_psk "$WLED_MQTT_PSK" \
  --arg hue_key "$WLED_HUE_KEY" \
  --arg ota_pwd "$WLED_OTA_PASSWORD" '{
  nw: { ins: [ { psk: $wifi_psk } ] },
  ap: { psk: $ap_psk },
  if: { mqtt: { psk: $mqtt_psk }, hue: { key: $hue_key } },
  pin: "",
  ota: { pwd: $ota_pwd, lock: false, "lock-wifi": false, aota: true }
}' > "$BAKED_WSEC"

echo "Wrote $BAKED_CFG and $BAKED_WSEC"
```

- [ ] **Step 2: Run**

```bash
./tools/mass-flash/build-fs.sh
```
Expected: `Wrote tools/mass-flash/build/cfg-baked.json and tools/mass-flash/build/wsec-baked.json`.

- [ ] **Step 3: Verify transformation**

```bash
jq '.nw.ins[0] | has("psk")' tools/mass-flash/build/wsec-baked.json
```
Expected: `true`. Do not print the credential value.

```bash
jq '.nw.ins[0] | has("pskl")' tools/mass-flash/build/cfg-baked.json
```
Expected: `false`.

- [ ] **Step 4: Commit**

```bash
git add tools/mass-flash/build-fs.sh
git commit -m "build-fs.sh: generate wsec from env credentials"
```

---

## Task 5: Build LittleFS image

**Files:**
- Modify: `tools/mass-flash/build-fs.sh`

**LittleFS sizing rationale:** WLED ESP8266 stock builds using the 4m1m layout reserve a **1,024,000 byte** LittleFS partition starting at flash offset `0x300000`. WLED 0.15 on ESP8266 uses LittleFS v2.0 with `name_max=32`, so the image is built with `littlefs-python` rather than `brew mklittlefs`.

- [ ] **Step 1: Append LittleFS build block**

Add to `tools/mass-flash/build-fs.sh`:

```bash
FS_STAGE="$BUILD_DIR/fs-stage"
LITTLEFS_BIN="$BUILD_DIR/littlefs.bin"

rm -rf "$FS_STAGE"
mkdir -p "$FS_STAGE"
cp "$BAKED_CFG"  "$FS_STAGE/cfg.json"
cp "$BAKED_WSEC" "$FS_STAGE/wsec.json"
cp "$WLED_DIR/wled_presets_experts-live-5-years.json" "$FS_STAGE/presets.json"
cp "$WLED_DIR/wled_ledmap.json" "$FS_STAGE/ledmap.json"

python3 - "$FS_STAGE" "$LITTLEFS_BIN" <<'PY'
import sys, os
from littlefs import LittleFS, UserContext

stage, out = sys.argv[1], sys.argv[2]
BLOCK_SIZE, BLOCK_COUNT = 8192, 125

ctx = UserContext(BLOCK_SIZE * BLOCK_COUNT)
fs = LittleFS(
    context=ctx,
    block_size=BLOCK_SIZE,
    block_count=BLOCK_COUNT,
    name_max=32,
    disk_version=0x00020000,
    mount=False,
)
fs.format()
fs.mount()

for fname in sorted(os.listdir(stage)):
    with open(os.path.join(stage, fname), 'rb') as r:
        data = r.read()
    with fs.open('/' + fname, 'wb') as w:
        w.write(data)
    print(f"  /{fname} ({len(data)} bytes)")

fs.unmount()
with open(out, 'wb') as f:
    f.write(bytes(ctx.buffer))
PY

echo "Wrote $LITTLEFS_BIN ($(stat -f%z "$LITTLEFS_BIN") bytes)"
```

- [ ] **Step 2: Run**

```bash
./tools/mass-flash/build-fs.sh
```
Expected: prints size of `littlefs.bin`. File size should equal `1024000` bytes.

- [ ] **Step 3: Verify contents**

```bash
python3 - <<'PY'
from littlefs import LittleFS, UserContext
with open('tools/mass-flash/build/littlefs.bin', 'rb') as f:
    ctx = UserContext(bytearray(f.read()))
fs = LittleFS(context=ctx, block_size=8192, block_count=125, name_max=32, disk_version=0x00020000)
print(fs.listdir('/'))
PY
```
Expected: lists `cfg.json`, `wsec.json`, `presets.json`, `ledmap.json` with non-zero sizes.

- [ ] **Step 4: Commit**

```bash
git add tools/mass-flash/build-fs.sh
git commit -m "build-fs.sh: build LittleFS image from wled/ configs"
```

---

## Task 6: flash.sh port auto-detection

**Files:**
- Create: `tools/mass-flash/flash.sh`

- [ ] **Step 1: Write flash.sh with port detection**

`tools/mass-flash/flash.sh`:
```bash
#!/usr/bin/env bash
set -euo pipefail

SCRIPT_DIR="$(cd "$(dirname "${BASH_SOURCE[0]}")" && pwd)"
BUILD_DIR="$SCRIPT_DIR/build"
FIRMWARE_BIN="$BUILD_DIR/WLED_0.15.0_ESP8266.bin"
LITTLEFS_BIN="$BUILD_DIR/littlefs.bin"
LITTLEFS_OFFSET=0x300000

if [[ ! -f "$FIRMWARE_BIN" || ! -f "$LITTLEFS_BIN" ]]; then
  echo "Build artifacts missing. Run ./build-fs.sh first." >&2
  exit 1
fi

detect_port() {
  # CP210x on macOS appears as /dev/cu.usbserial-*, CH340 as /dev/cu.wchusbserial-*
  local matches=()
  for p in /dev/cu.usbserial-* /dev/cu.wchusbserial-* /dev/cu.SLAB_USBtoUART; do
    [[ -e "$p" ]] && matches+=("$p")
  done
  if [[ ${#matches[@]} -eq 0 ]]; then
    echo "No USB-serial device found. Plug in an ESP8266 and retry." >&2
    exit 1
  fi
  if [[ ${#matches[@]} -gt 1 ]]; then
    echo "Multiple USB-serial devices found:" >&2
    printf '  %s\n' "${matches[@]}" >&2
    echo "Disconnect all but one and retry." >&2
    exit 1
  fi
  echo "${matches[0]}"
}

PORT="$(detect_port)"
echo "Detected port: $PORT"
```

- [ ] **Step 2: Make executable**

```bash
chmod +x tools/mass-flash/flash.sh
```

- [ ] **Step 3: Verify (no board plugged in)**

```bash
./tools/mass-flash/flash.sh
```
Expected: `No USB-serial device found. Plug in an ESP8266 and retry.` and exit code 1.

- [ ] **Step 4: Verify (one board plugged in)**

Plug in one ESP8266 via USB, then:
```bash
./tools/mass-flash/flash.sh
```
Expected: `Detected port: /dev/cu.usbserial-XXXX` (or `wchusbserial-XXXX`), then exits cleanly (flashing not yet implemented).

- [ ] **Step 5: Commit**

```bash
git add tools/mass-flash/flash.sh
git commit -m "flash.sh: USB-serial port auto-detection"
```

---

## Task 7: flash.sh — esptool write-flash + IP discovery

**Files:**
- Modify: `tools/mass-flash/flash.sh`

- [ ] **Step 1: Append flash + discovery block**

Add at the bottom of `tools/mass-flash/flash.sh`:

```bash
echo "Writing firmware + LittleFS..."
esptool --chip esp8266 --port "$PORT" write-flash \
  0x0                "$FIRMWARE_BIN" \
  "$LITTLEFS_OFFSET" "$LITTLEFS_BIN"

echo "Reading MAC..."
mac_output=$(esptool --chip esp8266 --port "$PORT" read-mac 2>&1)
mac=$(printf '%s\n' "$mac_output" | awk '/^MAC:/ {print $2; exit}')
echo "MAC: $mac"
echo "Done. Unplug and insert the next board."
```

- [ ] **Step 2: Verify `esptool` is available**

```bash
esptool version
```
Expected: version string.

- [ ] **Step 3: Flash one test board**

Plug in one ESP8266, then:
```bash
./tools/mass-flash/flash.sh
```
Expected output (summarized):
- `Writing firmware + LittleFS...` → two write blocks, both end `Hash of data verified.`
- `Reading MAC...` → shows the board MAC address
- IP discovery prints a URL after the board joins Wi-Fi
- `Done. Unplug and insert the next board.`

- [ ] **Step 4: Verify the flashed device**

Within a minute after flashing:
- Device joins the configured Wi-Fi network automatically (check router DHCP list or `http://expertslive.local`).
- LEDs begin playing the Experts Live boot playlist.
- WLED web UI loads and shows all presets and the correct device name.

If all three check out, proceed. If any fails, stop and debug before continuing.

- [ ] **Step 5: Commit**

```bash
git add tools/mass-flash/flash.sh
git commit -m "flash.sh: erase, write firmware+fs, verify via serial"
```

---

## Task 8: ~~Discover BG image URL field name~~ (DROPPED)

**Investigation outcome:** In WLED 0.15, the "BG image URL" setting is stored in the browser's `localStorage` (via the `wledUiCfg` key), not on the device. There is no server-side field to bake. The `skin.css` fallback also requires the browser's "Enable custom CSS" toggle (`comp.css` in localStorage) which is also browser-local. Therefore no device-side mechanism to propagate the BG image to every recipient exists in stock WLED 0.15.

**Decision:** drop Task 8 and Task 9. The BG image becomes an optional one-time per-browser step, documented in the tool README. The baked device config (boot playlist, LED map, Wi-Fi, presets) is unchanged by this decision.

---

## ~~Task 8/9: Bake BG URL~~ (DROPPED)

WLED 0.15 stores the UI background URL in browser `localStorage`, not on the device. The mass-flash image therefore cannot bake this setting. The README documents it as an optional one-time per-browser step instead.

---

## Task 10: Loop mode in flash.sh

**Files:**
- Modify: `tools/mass-flash/flash.sh`

- [ ] **Step 1: Wrap the main block in a loop when `--loop` is passed**

Restructure `tools/mass-flash/flash.sh` so the existing single-flash logic lives in a function `flash_one()`, and add a `--loop` dispatcher at the end. Final structure:

```bash
#!/usr/bin/env bash
set -euo pipefail

SCRIPT_DIR="$(cd "$(dirname "${BASH_SOURCE[0]}")" && pwd)"
BUILD_DIR="$SCRIPT_DIR/build"
FIRMWARE_BIN="$BUILD_DIR/WLED_0.15.0_ESP8266.bin"
LITTLEFS_BIN="$BUILD_DIR/littlefs.bin"
LITTLEFS_OFFSET=0x300000

if [[ ! -f "$FIRMWARE_BIN" || ! -f "$LITTLEFS_BIN" ]]; then
  echo "Build artifacts missing. Run ./build-fs.sh first." >&2
  exit 1
fi

detect_port() {
  local matches=()
  for p in /dev/cu.usbserial-* /dev/cu.wchusbserial-* /dev/cu.SLAB_USBtoUART; do
    [[ -e "$p" ]] && matches+=("$p")
  done
  if [[ ${#matches[@]} -eq 0 ]]; then return 1; fi
  if [[ ${#matches[@]} -gt 1 ]]; then
    echo "Multiple USB-serial devices found:" >&2
    printf '  %s\n' "${matches[@]}" >&2
    return 2
  fi
  echo "${matches[0]}"
}

wait_for_port() {
  echo "Waiting for board to be plugged in..."
  while true; do
    local port
    port="$(detect_port 2>/dev/null || true)"
    if [[ -n "$port" ]]; then echo "$port"; return 0; fi
    sleep 1
  done
}

wait_for_disconnect() {
  local port="$1"
  echo "Unplug the board to flash the next one."
  while [[ -e "$port" ]]; do sleep 1; done
  echo "Board unplugged."
}

flash_one() {
  local port="$1"
  echo "Detected port: $port"
  echo "Writing firmware + LittleFS..."
  esptool --chip esp8266 --port "$port" write-flash \
    0x0               "$FIRMWARE_BIN" \
    "$LITTLEFS_OFFSET" "$LITTLEFS_BIN"
  echo "Reading MAC..."
  mac_output=$(esptool --chip esp8266 --port "$port" read-mac 2>&1)
  mac=$(printf '%s\n' "$mac_output" | awk '/^MAC:/ {print $2; exit}')
  echo "MAC: $mac"
  echo "Done."
}

if [[ "${1:-}" == "--loop" ]]; then
  count=0
  while true; do
    port="$(wait_for_port)"
    count=$((count + 1))
    echo "--- Board #$count ---"
    flash_one "$port"
    wait_for_disconnect "$port"
    echo ""
  done
else
  port="$(detect_port)" || {
    echo "No USB-serial device found. Plug in an ESP8266 and retry." >&2
    exit 1
  }
  flash_one "$port"
  echo "Unplug and insert the next board."
fi
```

- [ ] **Step 2: Verify single-shot still works**

```bash
./tools/mass-flash/flash.sh
```
Expected: flashes the currently plugged-in board (or errors cleanly if none).

- [ ] **Step 3: Verify loop mode**

```bash
./tools/mass-flash/flash.sh --loop
```
Expected: prints `Waiting for board to be plugged in...`. Plug in a board — it flashes, then prints `Unplug the board to flash the next one.`. Unplug — script returns to waiting. Ctrl-C to exit.

Do not flash the full batch in this step. Just verify the state machine works for 2 boards.

- [ ] **Step 4: Commit**

```bash
git add tools/mass-flash/flash.sh
git commit -m "flash.sh: loop mode for sequential mass-flash"
```

---

## Task 11: Mass-flash run + documentation

**Files:**
- Modify: `tools/mass-flash/README.md`

- [ ] **Step 1: Update README with final workflow**

Append to `tools/mass-flash/README.md`:

```markdown
## Mass-flashing multiple boards

1. Run `./build-fs.sh` once. Commits any new firmware to the build cache.
2. Run `./flash.sh --loop`.
3. For each board:
   - Plug into USB
   - Wait for "Done." message (~30–45s)
   - Unplug
4. Ctrl-C when done.

Expected total time: 25–40 minutes.

## Troubleshooting

**Board not detected:** Check USB cable (some are charge-only). For CH340 clones, install the WCH driver.

**`Failed to connect to ESP8266` from esptool:** Hold GPIO0 to GND while plugging in, then release. Some clone boards don't auto-reset.

**Device joins Wi-Fi but no LEDs:** Power delivery. The first flash draws heavy current — USB may not provide enough for the LED strip. Powering the LED strip from its own supply during flashing is the fix.

**Device boots but doesn't join Wi-Fi:** Verify the required `WLED_*` environment variables were set before building. Rebuild with `./build-fs.sh` if needed.
```

- [ ] **Step 2: Flash all boards**

```bash
./tools/mass-flash/flash.sh --loop
```
Work through all boards. After each, do a quick smoke check on one representative board mid-run (boot playlist plays, joins Wi-Fi, UI loads with correct BG).

- [ ] **Step 3: Commit**

```bash
git add tools/mass-flash/README.md
git commit -m "Document mass-flash workflow and troubleshooting"
```

---

## Completion Checklist

- [ ] `./build-fs.sh` runs cleanly on a fresh checkout.
- [ ] `./flash.sh` (single) flashes one board in under a minute.
- [ ] `./flash.sh --loop` state machine works across 2+ boards.
- [ ] Test board: joins the configured Wi-Fi network, plays boot playlist, shows correct UI background without any manual step.
- [ ] All boards flashed and spot-checked.
- [ ] README documents workflow + troubleshooting.
- [ ] All intermediate commits pushed (or batched for a single PR — your call).

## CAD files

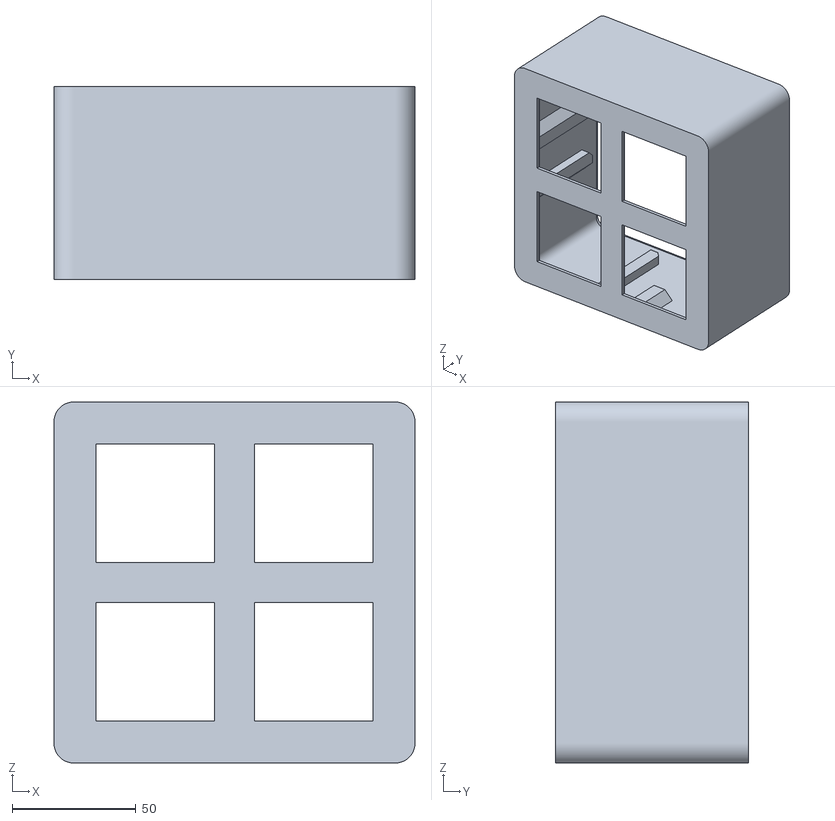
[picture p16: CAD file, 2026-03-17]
model-files/experts-live-high-five-hive-housing-main.stl
146.0 x 78.0 x 146.0

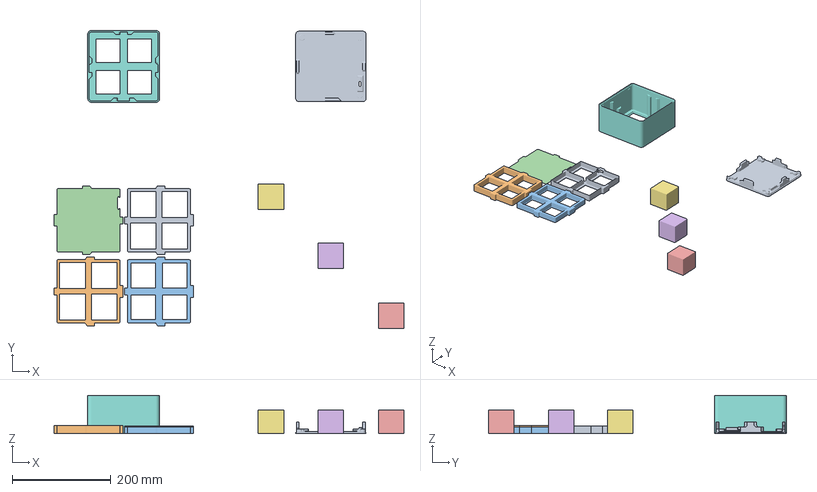
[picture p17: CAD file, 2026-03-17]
model-files/experts-live-high-five-hive.3mf
709.5 x 604.6 x 78.0 mm
Experts Live High Five Hive - 2 - LED Frame.stl
Experts Live High Five Hive - 1 - Cube Holder.stl
Experts Live High Five Hive - 3 - Cube Holder.stl
Experts Live High Five Hive - 3 - Cube Holder Plate.stl
Experts Live High Five Hive - Housing - main.stl
Experts Live High Five Hive - Part 48

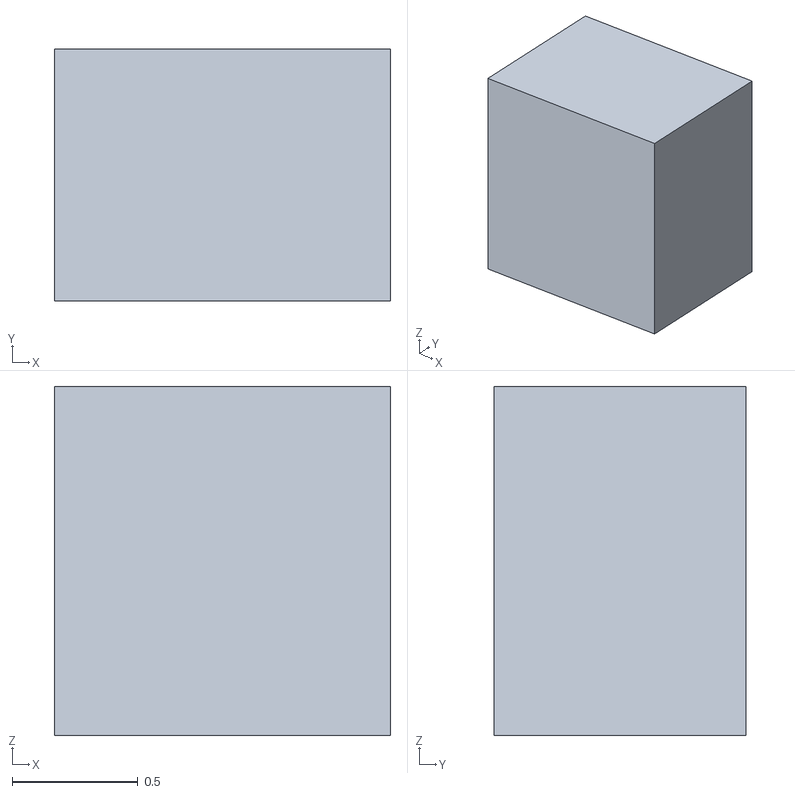
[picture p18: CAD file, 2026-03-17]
model-files/experts-live-high-five-hive-housing-cover-07-i-2.stl
1.34 x 1.00 x 1.39

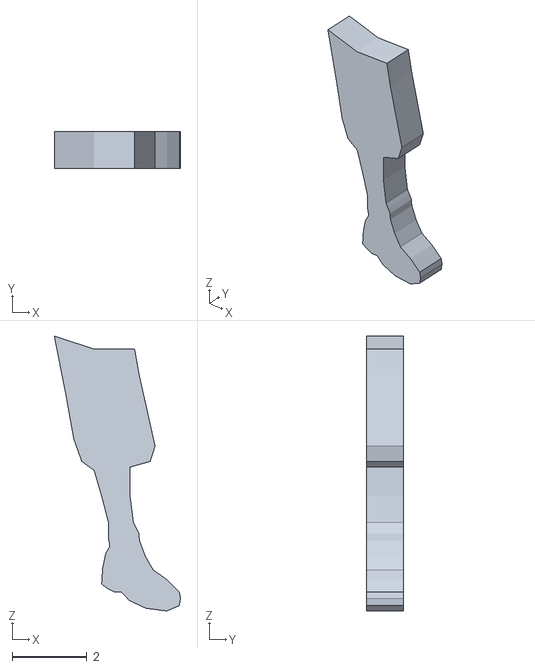
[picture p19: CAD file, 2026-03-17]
model-files/experts-live-high-five-hive-housing-cover-10-mascotte-2-2.stl
3.37 x 1.00 x 7.35

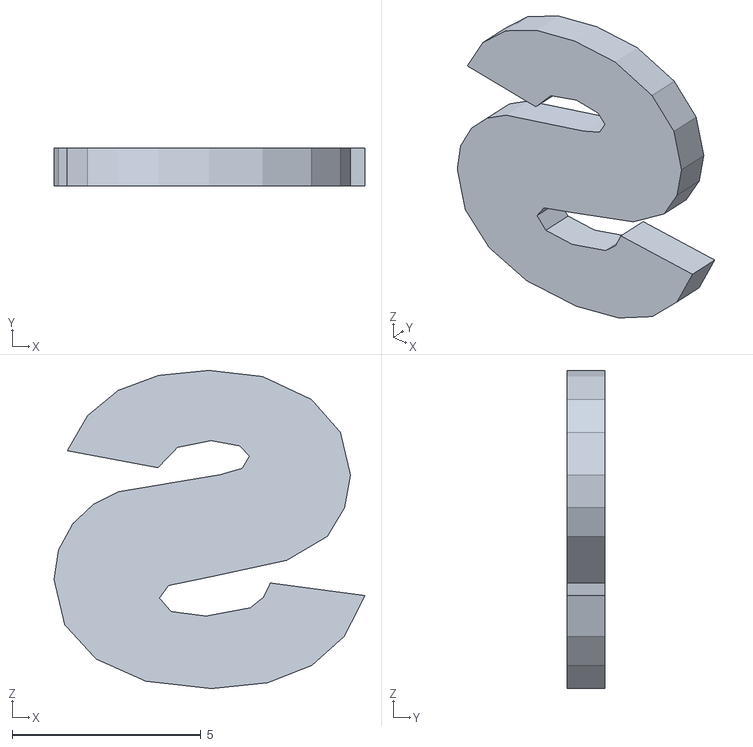
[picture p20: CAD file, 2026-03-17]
model-files/experts-live-high-five-hive-housing-cover-05-s.stl
8.25 x 1.00 x 8.44

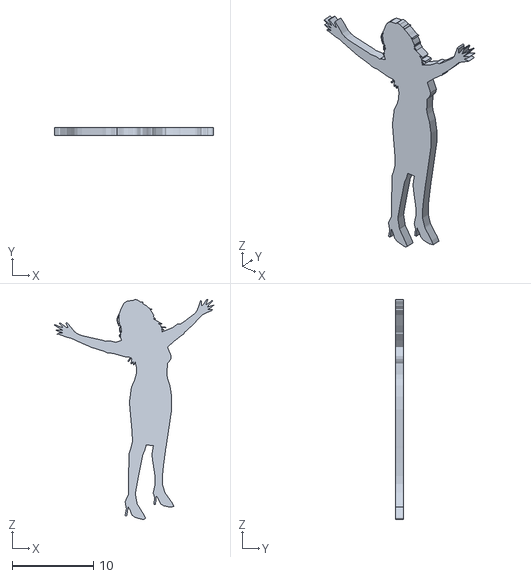
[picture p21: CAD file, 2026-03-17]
model-files/experts-live-high-five-hive-housing-cover-10-mascotte-3.stl
19.7 x 1.00 x 27.1

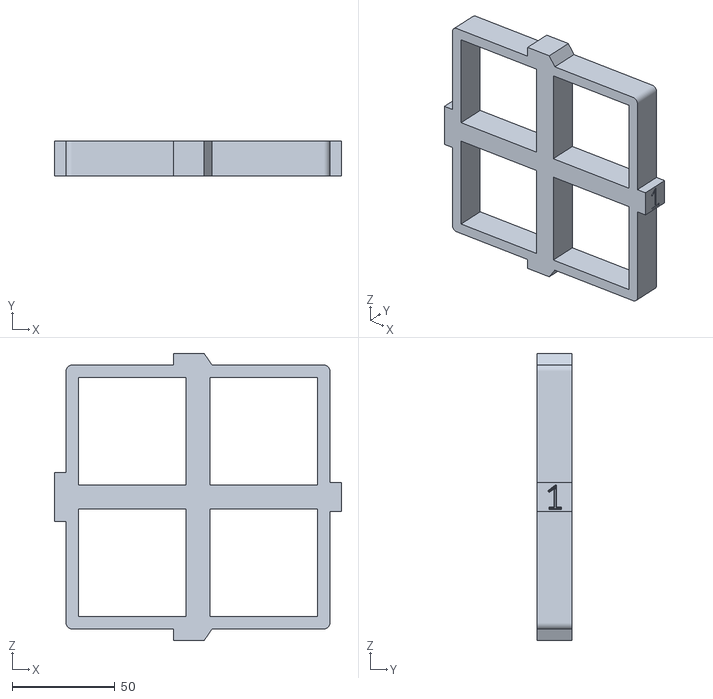
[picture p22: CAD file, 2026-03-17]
model-files/experts-live-high-five-hive-1-cube-holder.stl
139.6 x 17.0 x 139.6

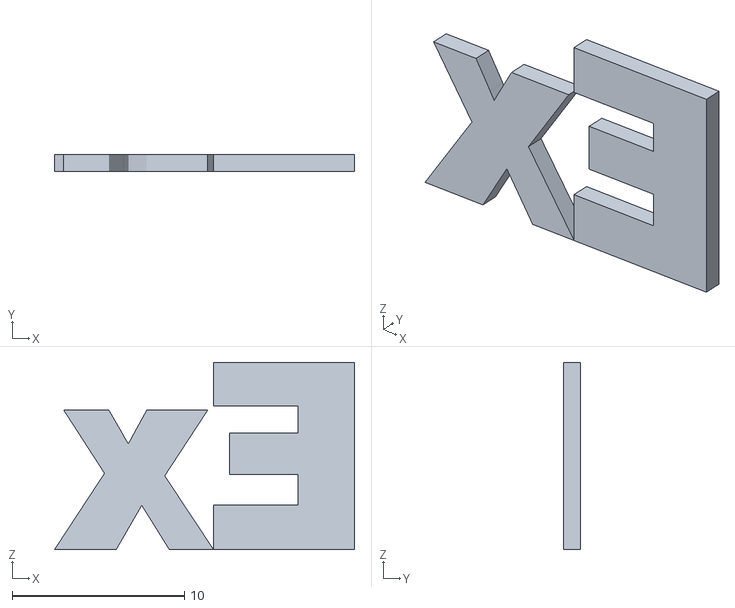
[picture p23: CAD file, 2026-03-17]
model-files/experts-live-high-five-hive-housing-cover-01-ex.stl
17.4 x 1.00 x 10.9

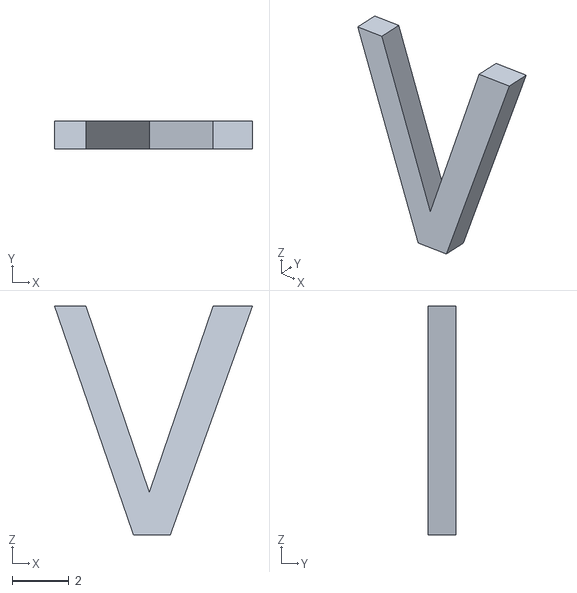
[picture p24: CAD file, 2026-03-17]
model-files/experts-live-high-five-hive-housing-cover-08-v.stl
6.96 x 1.00 x 8.04

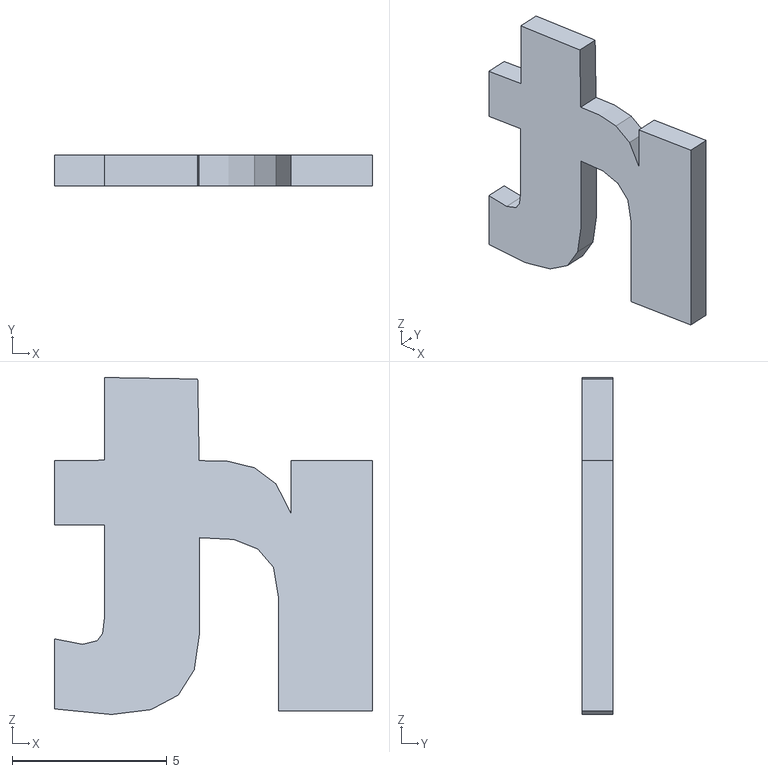
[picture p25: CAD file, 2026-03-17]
model-files/experts-live-high-five-hive-housing-cover-04-rt.stl
10.3 x 1.00 x 10.9

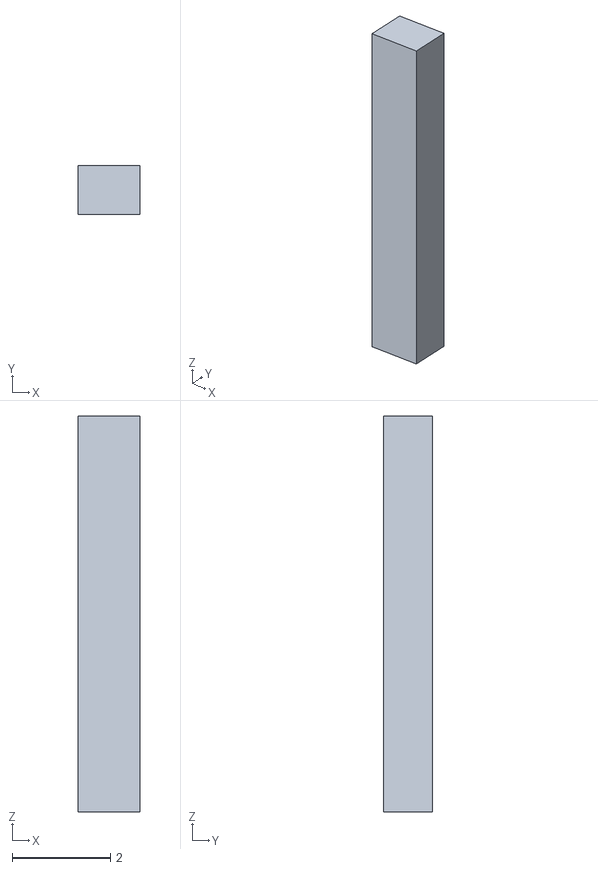
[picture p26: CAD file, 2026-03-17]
model-files/experts-live-high-five-hive-housing-cover-07-i-1.stl
1.25 x 1.00 x 8.04

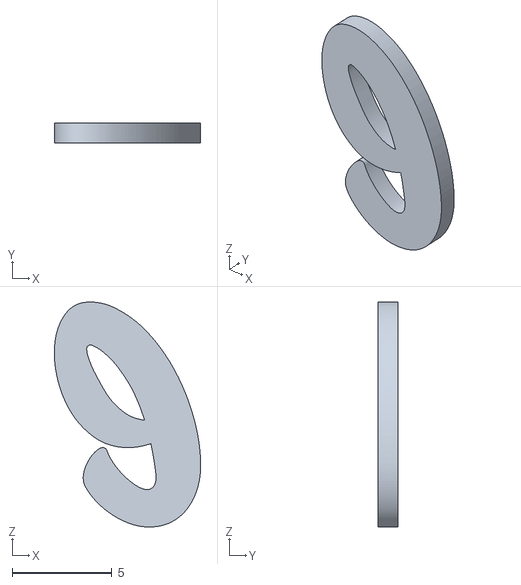
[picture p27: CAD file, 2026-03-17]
model-files/experts-live-high-five-hive-housing-cover-13-E.stl
7.33 x 1.00 x 11.3

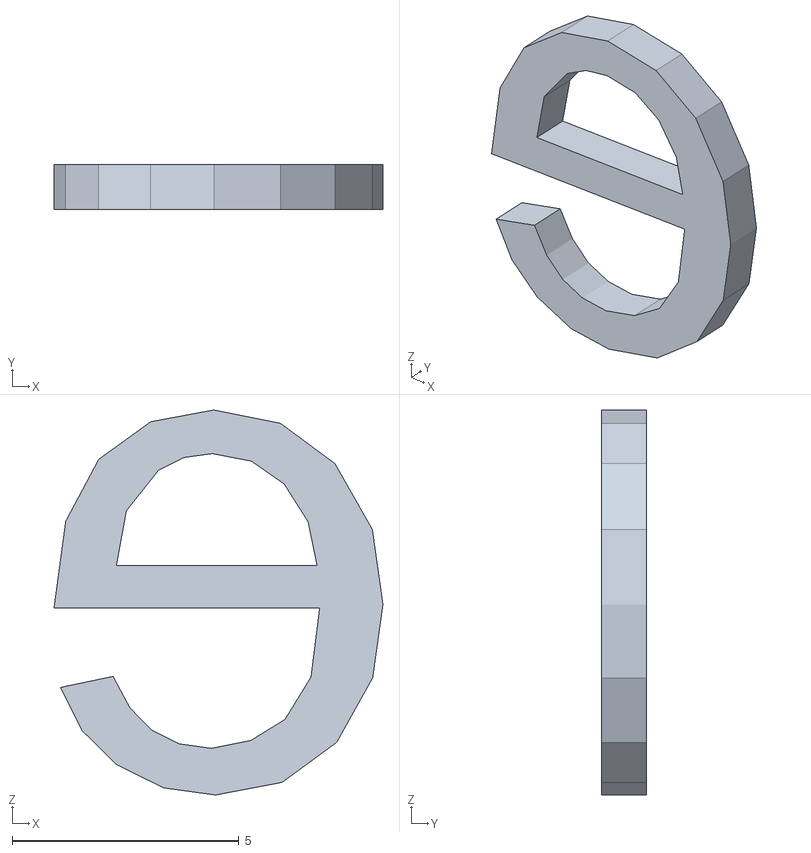
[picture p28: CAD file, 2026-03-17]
model-files/experts-live-high-five-hive-housing-cover-09-e.stl
7.25 x 1.00 x 8.49

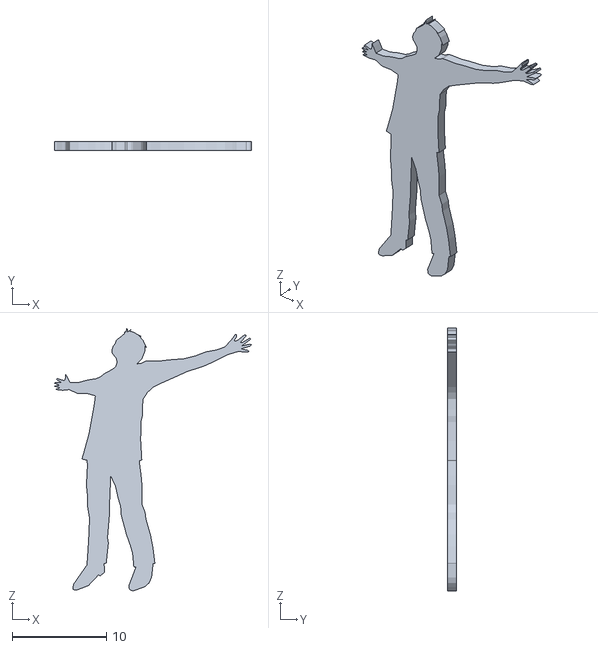
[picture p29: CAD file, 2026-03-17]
model-files/experts-live-high-five-hive-housing-cover-10-mascotte-1.stl
21.0 x 1.00 x 28.0

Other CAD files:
model-files/experts-live-high-five-hive-3-cube-holder.stl
model-files/experts-live-high-five-hive-housing-cover-14-A.stl
model-files/experts-live-high-five-hive-housing-cover-10-mascotte-2-1.stl
model-files/experts-live-high-five-hive-housing-cover-02-p.stl
model-files/experts-live-high-five-hive-2-led-frame.stl
model-files/experts-live-high-five-hive-3-cube-holder-plate.stl
model-files/experts-live-high-five-hive-housing-cover-03-e.stl
model-files/experts-live-high-five-hive-housing-cover-06-l.stl
model-files/experts-live-high-five-hive-housing-cover-10-mascotte-2-3.stl
model-files/experts-live-high-five-hive-housing-cover-11-5.stl
model-files/experts-live-high-five-hive-housing-cover-12-Y.stl
model-files/experts-live-high-five-hive-housing-cover-15-R.stl
model-files/experts-live-high-five-hive-housing-cover-16-S.stl
model-files/experts-live-high-five-hive-housing-cover.stl
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

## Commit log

2026-03-17 Initial upload
    [Experts Live High Five Hive - 1 - Cube Holder.stl, Experts Live High Five Hive - 2 - LED Frame.stl, Experts Live High Five Hive - 3 - Cube Holder Plate.stl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]
2026-03-17 Renamed files to lowercase
    [experts-live-high-five-hive-1-cube-holder.stl, experts-live-high-five-hive-2-led-frame.stl, experts-live-high-five-hive-3-cube-holder-plate.stl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]
2026-03-17 Uploaded 3MF project file
    [experts-live-high-five-hive.3mf]
2026-03-17 Latest version of 3MF
    [experts-live-high-five-hive.3mf]
2026-05-01 Mass-flash tool: USB-only WLED provisioning for multiple boards
    Adds USB-only WLED mass-flash tooling with environment-supplied credentials, LittleFS provisioning, MAC/IP discovery, and review fixes.
